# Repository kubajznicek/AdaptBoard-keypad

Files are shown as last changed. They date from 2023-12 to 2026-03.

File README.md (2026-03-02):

# AdaptBoard keypad

Custom macropad with swappable modules, based on Key Boar 2040.
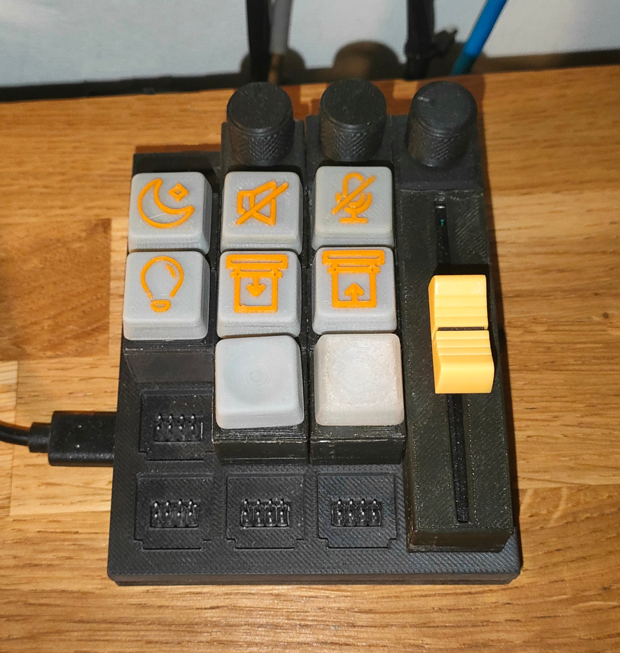
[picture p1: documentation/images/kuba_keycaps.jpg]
AdaptBoard grey keycaps


## Features

- swappable modules
- 4x5 customizable grid
- serial communication

#### Different modules
- key switch module
- potentiometer module
- slide potentiometer module
- lcd module
- joystick module

## Parts list

#### Base of the keypad
- [Kee Boar 2040](https://www.adafruit.com/product/5302)
- [Analog multiplexer](https://www.laskakit.cz/analogovy-multiplexer-16-kanalu-cd74hc4067/)
- custom [PCB](./pcb/)
- 3D printed case
- [pin header](https://www.laskakit.cz/dupont-2x40pin-2-54-mm-pinovy-pas/)*
- [pin header](https://www.laskakit.cz/dupont-40pin-2-54-mm-pinovy-pas/)* for KB2040 and Analog multiplexer
- any USB-C cable

#### Modules
- keyboard switch (any standard keyboard switch should work)
- [potenciometr](https://www.laskakit.cz/psotenciometr-posuvny-10kohm--modul/)*
- [linear potenciometr](https://www.laskakit.cz/potenciometr-rk097n-3-10k-linearni-10k--/)*
- [analog multiplexer](https://www.laskakit.cz/analogovy-multiplexer-16-kanalu-cd74hc4067/)*
- [joystick](https://www.laskakit.cz/joystick-2d-modul/)*
- [OLED display](https://www.laskakit.cz/oled-displej-modry-128x32-0-91--i2c/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)*
- [pin socket](https://www.laskakit.cz/dupont-2x20pin-2-54-mm-pinovy-pas--samice/)* 02x04
- 3D printed keycaps

<sub>*link to Czech e-shop. You may buy elsewhere, just make sure it is the same part model<sub>

## Build your own

for required parts see [Parts list](#parts-list)
Once you have all the parts, you can start building your own AdaptBoard keypad.

#### Soldering

1. Solder pin headers to the Kee Boar 2040 and to the Analog multiplexer
2. Solder first batch of headers to the custom PCB
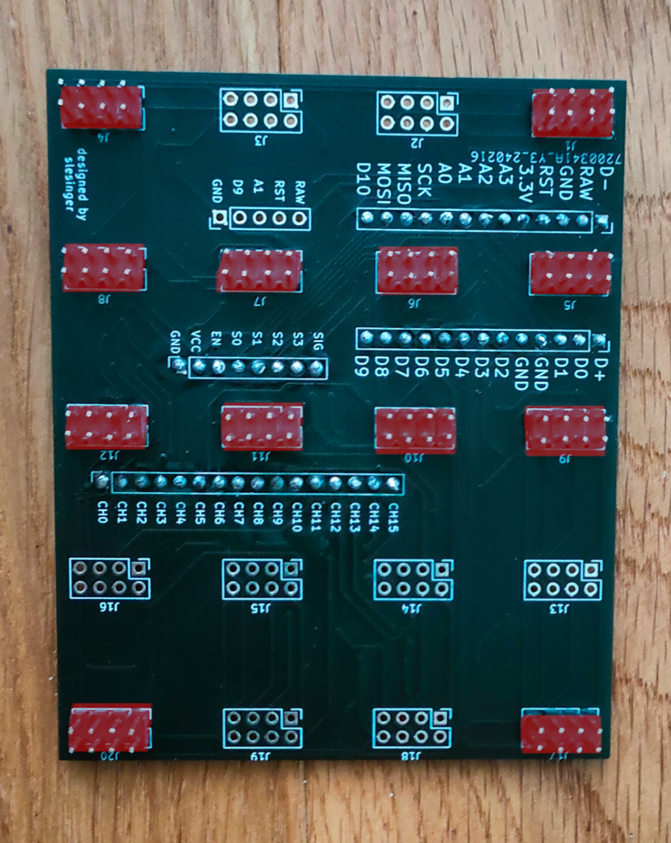
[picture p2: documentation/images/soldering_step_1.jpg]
soldering_step_1

3. Trim the headers on the Kee Boar 2040 and Analog multiplexer, so they are ~1mm above the PCB
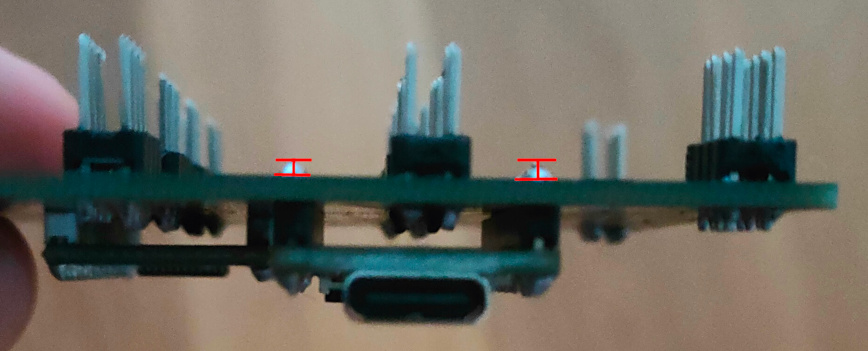
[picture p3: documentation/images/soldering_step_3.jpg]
soldering_step_3

Then solder the Kee Boar 2040 and Analog multiplexer to the back side of the PCB
4. Solder the remaining headers to the PCB

#### Assembling

@TODO

#### Programming
1. Install [CircuitPython](https://learn.adafruit.com/adafruit-kb2040/circuitpython) on your Kee Boar 2040 __Developed and tested on CircuitPython version 8.2.7__
2. Delete the `code.py` file from the CIRCUITPY drive
3. Upload our [firmware](./firmware/) to the CIRCUITPY drive
The final file structure should look like this:
```plaintext
CIRCUITPY
    analog_signal_processor.py
    boot_out.txt #circuitpy system file
    functions.py
    /lib
        /adafruit_display_text
        /adafruit_hid
        adafruit_pixelbuf.mpy
        neopixel.mpy
    main.py
    ssd1306_display.py
```
4. Go to [our App](https://adaptboard-c6996.web.app/) and create your own layout and configuration

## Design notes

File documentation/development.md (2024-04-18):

# Developing for AdaptBoard-keypad

AdaptBoard software is written in CircuitPython 8.2.7, a subset of Python 3. It is designed to be easy to use and to run on microcontrollers with small amounts of RAM and flash memory. CircuitPython is open source and available on [GitHub](https://github.com/adafruit/circuitpython).
[CircuitPython tricks](https://github.com/todbot/circuitpython-tricks)

## Getting Started

To get started, you'll need to install the latest version of CircuitPython for your board. Please follow the instructions in the [KB2040 docs](https://learn.adafruit.com/adafruit-kb2040/circuitpython) to install CircuitPython on your board.

## Dependencies

The following libraries are required for the AdaptBoard-keypad to work:

- adafruit_display_text
- adafruit_hid
- adafruit_pixelbuf.mpy
- neopixel.mpy

## Developing

**⚠️ Warning**

> Adafruit recommends their Mu editor for CircuitPython development, because other IDE may save the files corrupted. However, you can use your IDE of choice and the copy the files onto the board.

copying files to the board

```bash
cp -r main.py /media/$USER/CIRCUITPY/
```

## Enabling and disabling CircuitPython devices

CircuitPython has support for a number of devices. You can enable or disable these devices by editing the `boot.py` file on the CIRCUITPY drive.

```python
import usb_midi # type: ignore
usb_midi.disable()
```

[Adafruit device docs](https://learn.adafruit.com/customizing-usb-devices-in-circuitpython/circuitpy-midi-serial)

If you disabled `storage.disable_usb_drive()` in boot.py, you can enable it by entering safe mode. To enter safe mode, press the reset button twice.

When in safe mode **no code will be executed** and the CIRCUITPY drive will be mounted and you can edit the `boot.py` file.

**⚠️ Warning**

>**`boot.py` is only executed after a hard reset or a power cycle**

[Adafruit safe mode docs](https://learn.adafruit.com/circuitpython-safe-mode/overview)

## Debugging

programs for displaying output from serial port:
- Linux **screen** or **minicom**
- Windows **PuTTY**

### Steps
- Connect the board to your computer using a USB cable.
- The board should appear as a USB drive named CIRCUITPY.
    > If not you can enable it in safe mode by pressing the reset button twice. For more information see [Enabling and disabling CircuitPython devices](#enabling-and-disabling-circuitpython-devices)
- Find the serial port for the board.
    - On Windows, you can use the Device Manager to find the serial port.

    - On Linux, you can use the following command to list the serial ports:

    ```bash
    ls /dev/ttyACM*
    ``` 

- Connect to the serial port using the serial terminal program.
    - On Windows, you can use PuTTY to connect to the serial port.

    - On Linux, you can use the screen command to connect to the serial port.
    ```bash
    sudo screen /dev/ttyACM0 # replace with your port
    ```

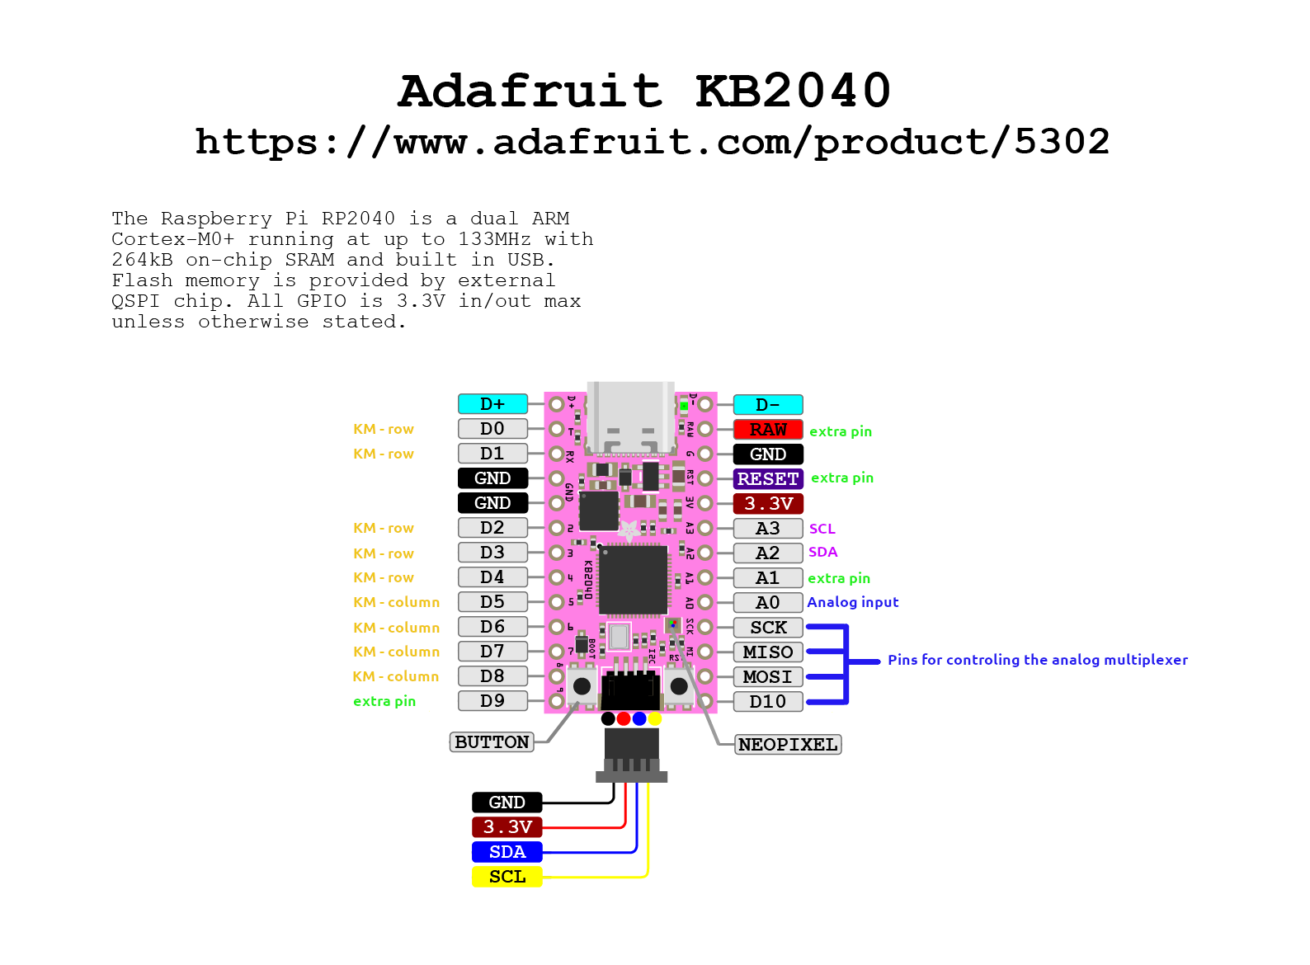
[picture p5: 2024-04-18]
documentation/images/Cutsom_Adafruit_KB2040_Pinout.png

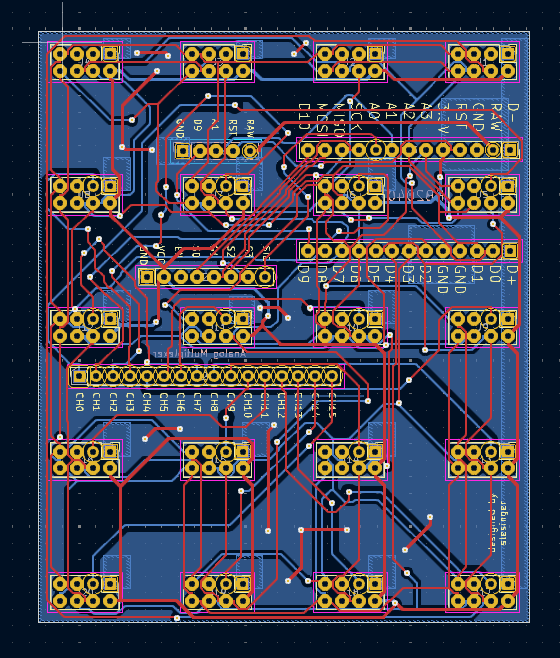
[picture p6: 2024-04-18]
documentation/images/pcb_KiCad_screenshot.png

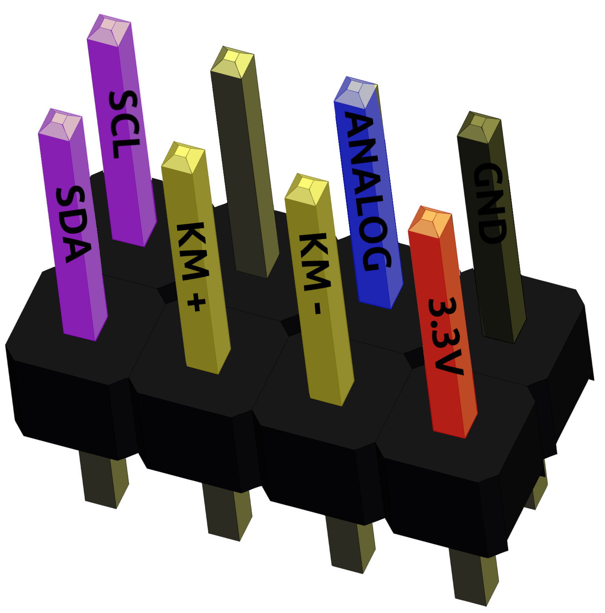
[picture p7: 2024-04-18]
documentation/images/header.png

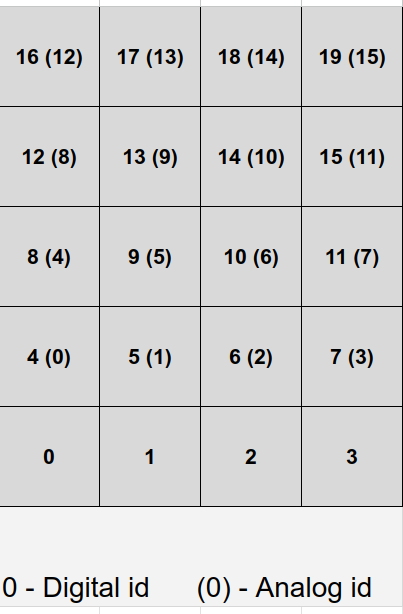
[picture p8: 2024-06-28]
documentation/images/grid_numbers.png

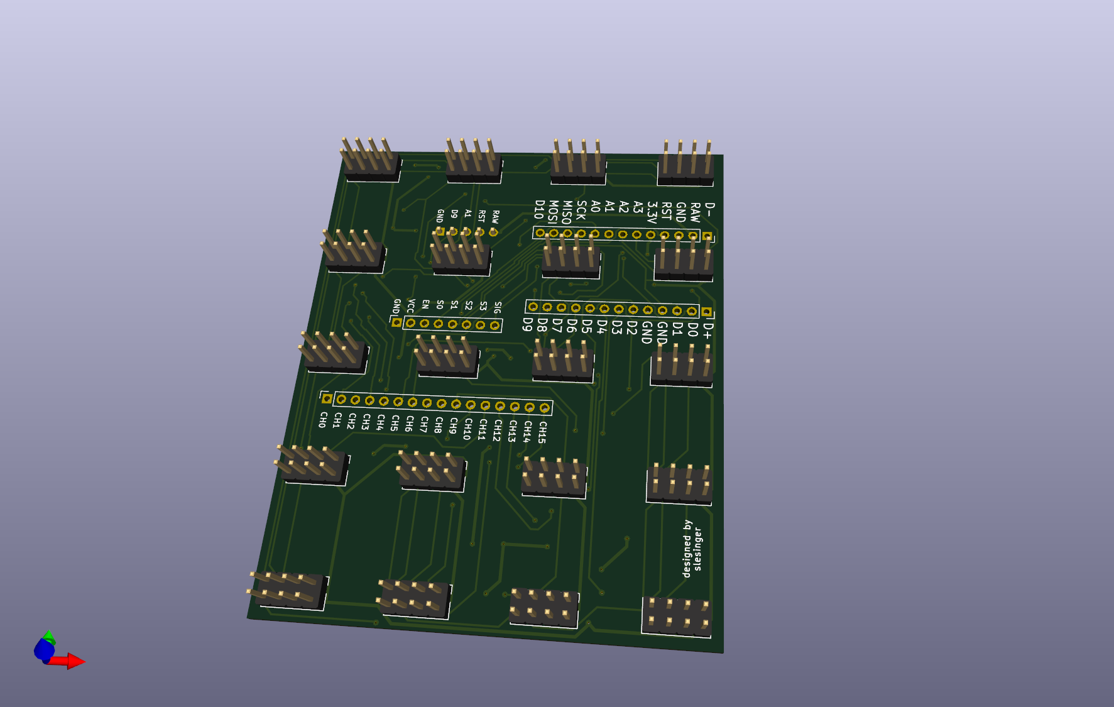
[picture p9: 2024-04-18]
documentation/images/pcb_3D.png

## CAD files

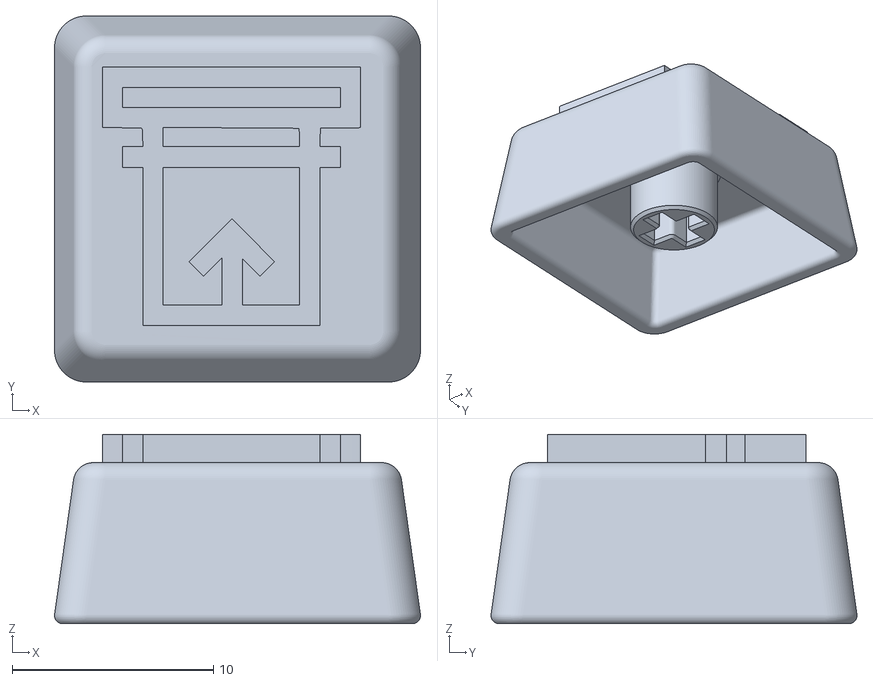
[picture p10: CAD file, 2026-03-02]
Adaptboard-models/keycaps/keycap_window_blind_up.stl
18.2 x 18.2 x 9.40

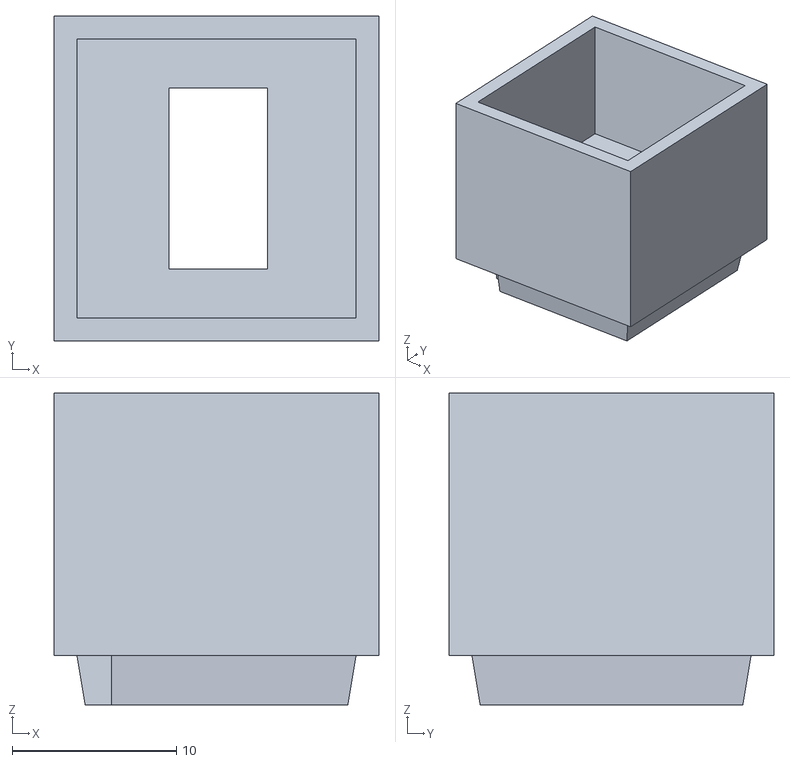
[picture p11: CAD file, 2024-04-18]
Adaptboard-models/Module_1x1_case.stl
19.8 x 19.8 x 19.0

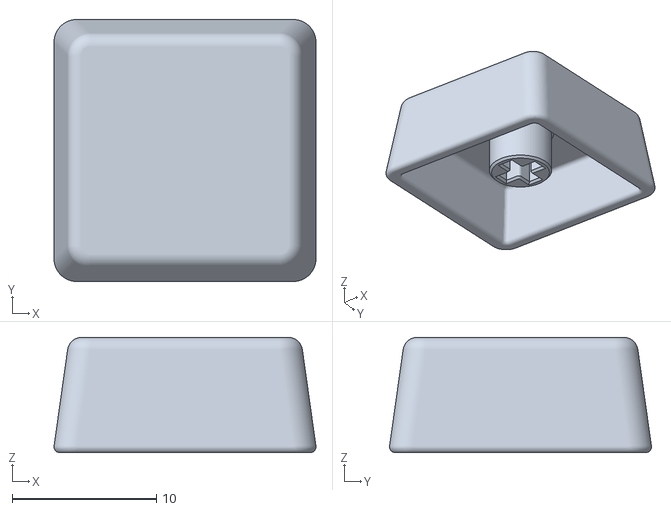
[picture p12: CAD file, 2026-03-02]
Adaptboard-models/keycaps/keycap_flat.stl
18.2 x 18.2 x 8.00

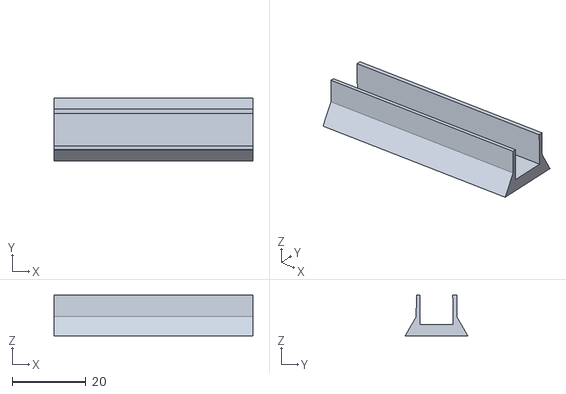
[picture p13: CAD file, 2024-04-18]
Adaptboard-models/Module_4x1_slider_arreter.stl
54.0 x 17.0 x 11.0

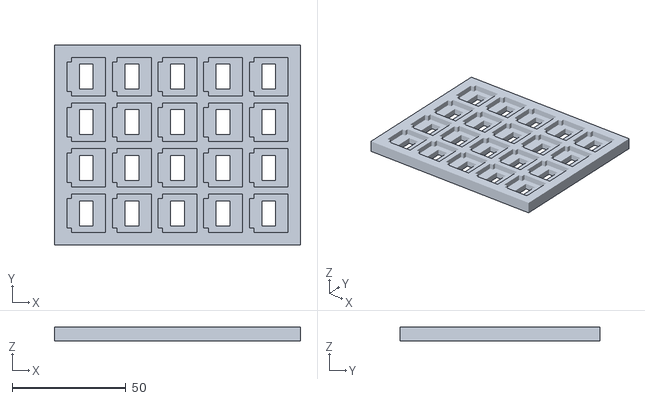
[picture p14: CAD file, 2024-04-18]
Adaptboard-models/Body_grid.stl
108.0 x 88.0 x 6.20

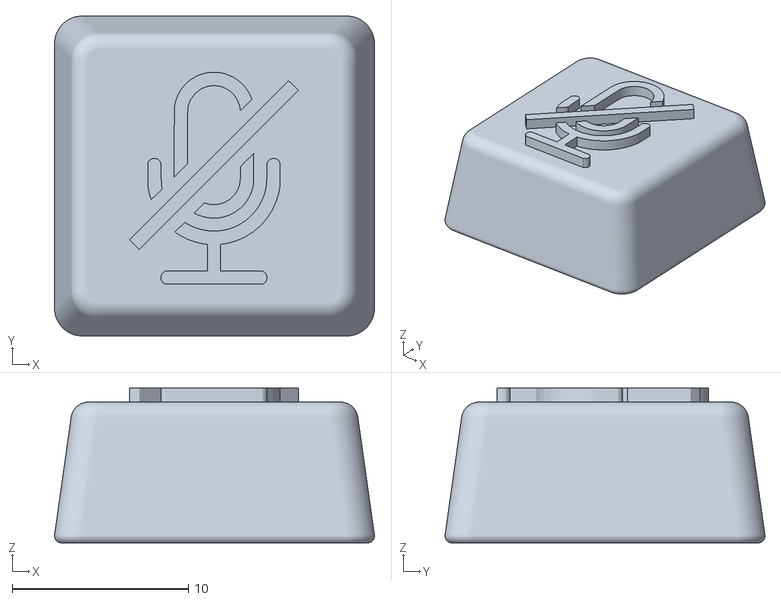
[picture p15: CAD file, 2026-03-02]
Adaptboard-models/keycaps/keycap_mic.stl
18.2 x 18.2 x 8.79

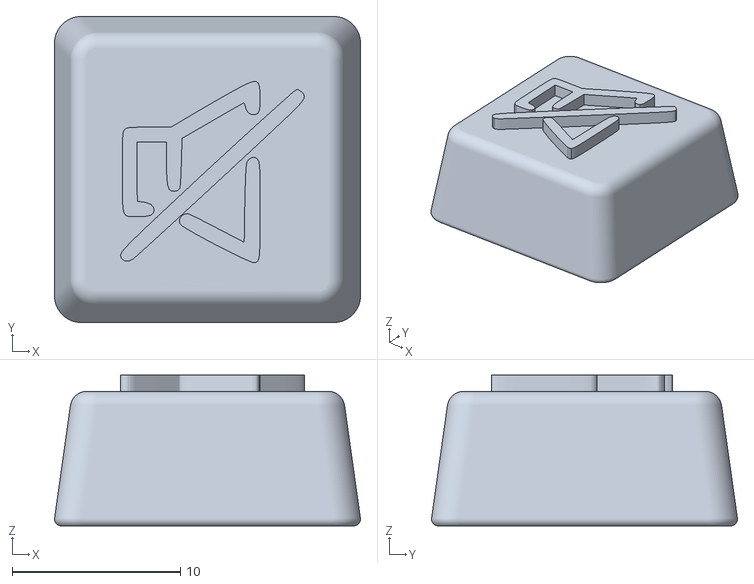
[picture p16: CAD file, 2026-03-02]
Adaptboard-models/keycaps/keycap_mute.stl
18.2 x 18.2 x 8.96

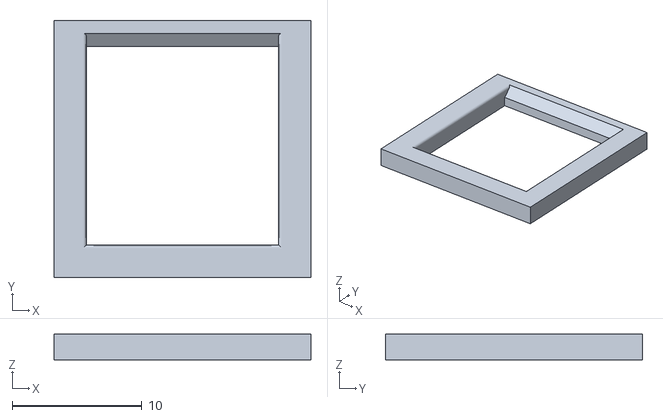
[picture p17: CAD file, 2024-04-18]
Adaptboard-models/Module_1x1_switch_lid.stl
19.8 x 19.8 x 2.00

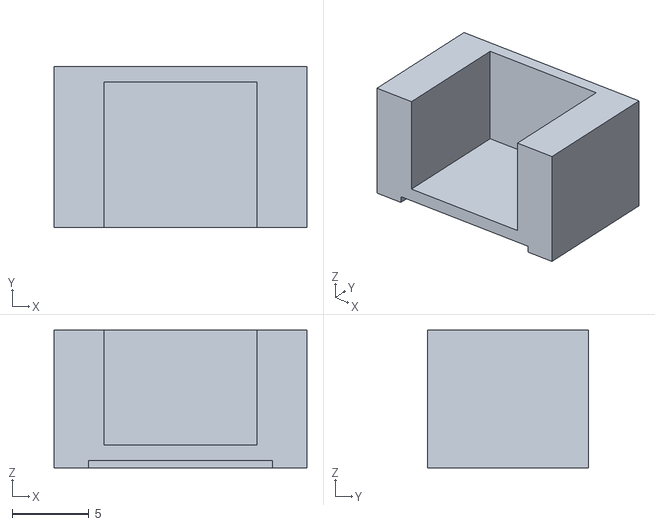
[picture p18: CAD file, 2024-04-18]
Adaptboard-models/Module_1x1_pot_arreter.stl
16.5 x 10.5 x 9.00

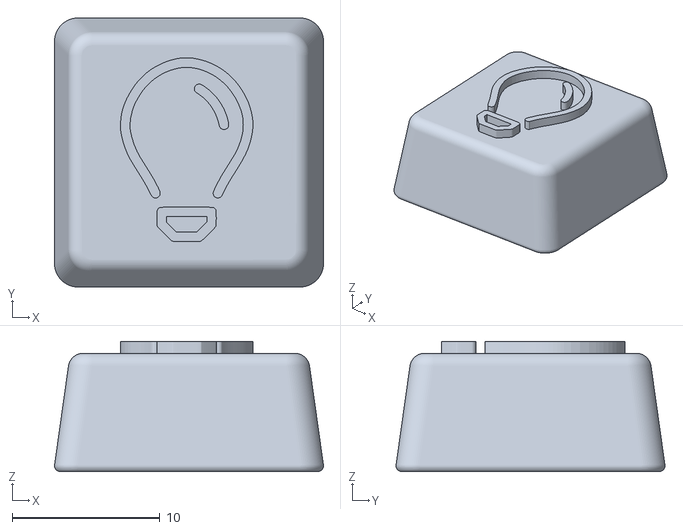
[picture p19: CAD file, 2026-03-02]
Adaptboard-models/keycaps/keycap_lightbulb.stl
18.2 x 18.2 x 8.81

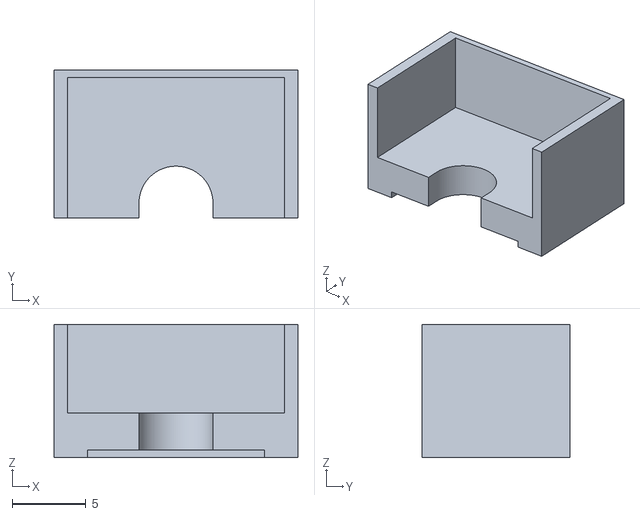
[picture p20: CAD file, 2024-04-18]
Adaptboard-models/Module_1x1_switch_arreter.stl
16.5 x 10.0 x 9.00

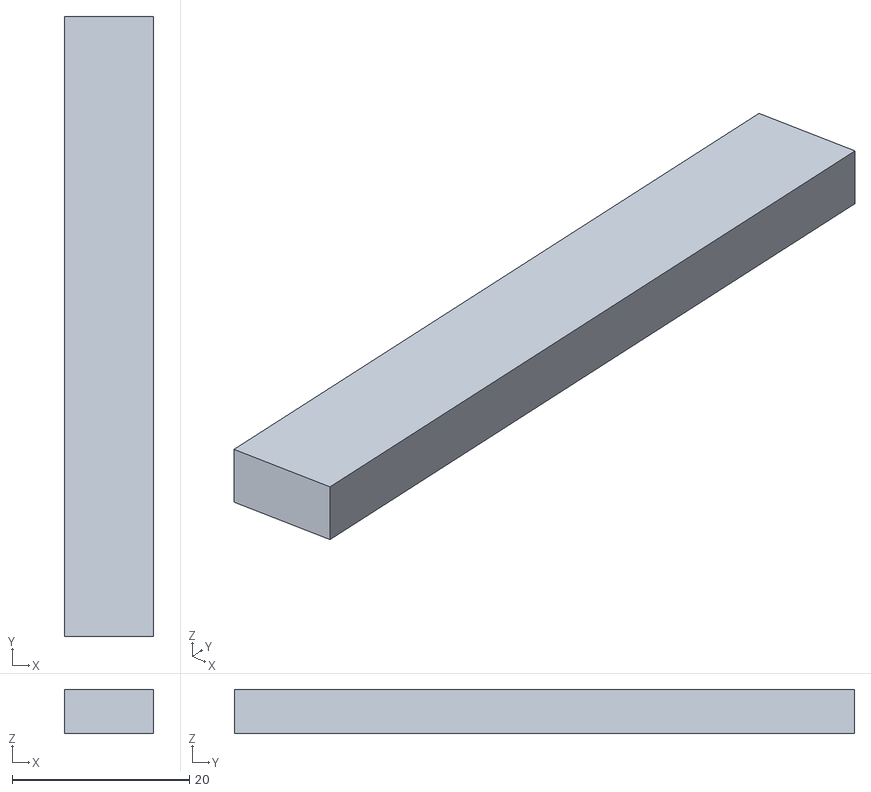
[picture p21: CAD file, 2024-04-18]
Adaptboard-models/Body_foot.stl
10.0 x 70.0 x 5.00

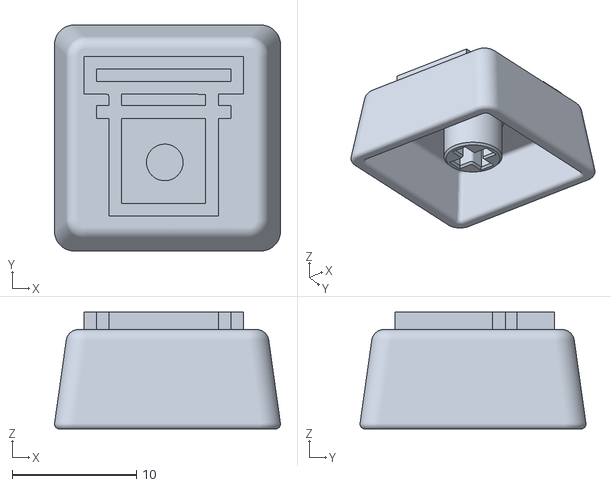
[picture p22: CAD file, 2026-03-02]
Adaptboard-models/keycaps/keycap_window_blind_stop.stl
18.2 x 18.2 x 9.40

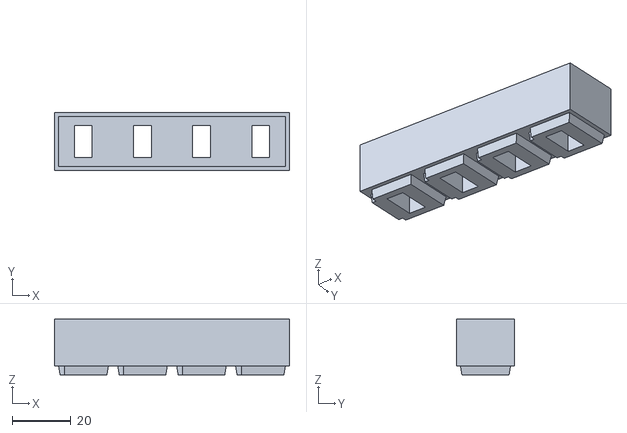
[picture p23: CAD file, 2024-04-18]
Adaptboard-models/Module_4x1_case.stl
79.8 x 19.8 x 19.0

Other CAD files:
Adaptboard-models/keycaps/keycap_window_blind_down.stl
Adaptboard-models/keycaps/keycap_keyboard_light.stl
Adaptboard-models/Body_bottom_cover.stl
Adaptboard-models/keycaps/keycap_discord_mute.stl
Adaptboard-models/AdaptBoard-Keypad.f3d
Adaptboard-models/Body_base.stl
Adaptboard-models/Body_case.stl
Adaptboard-models/Module_1x1_pot_lid.stl
Adaptboard-models/Module_4x1_slider_lid.stl
Adaptboard-models/Pot_soldering_holder.stl
Adaptboard-models/SC- top.stl
Adaptboard-models/keycaps/keycap_sleep.stl

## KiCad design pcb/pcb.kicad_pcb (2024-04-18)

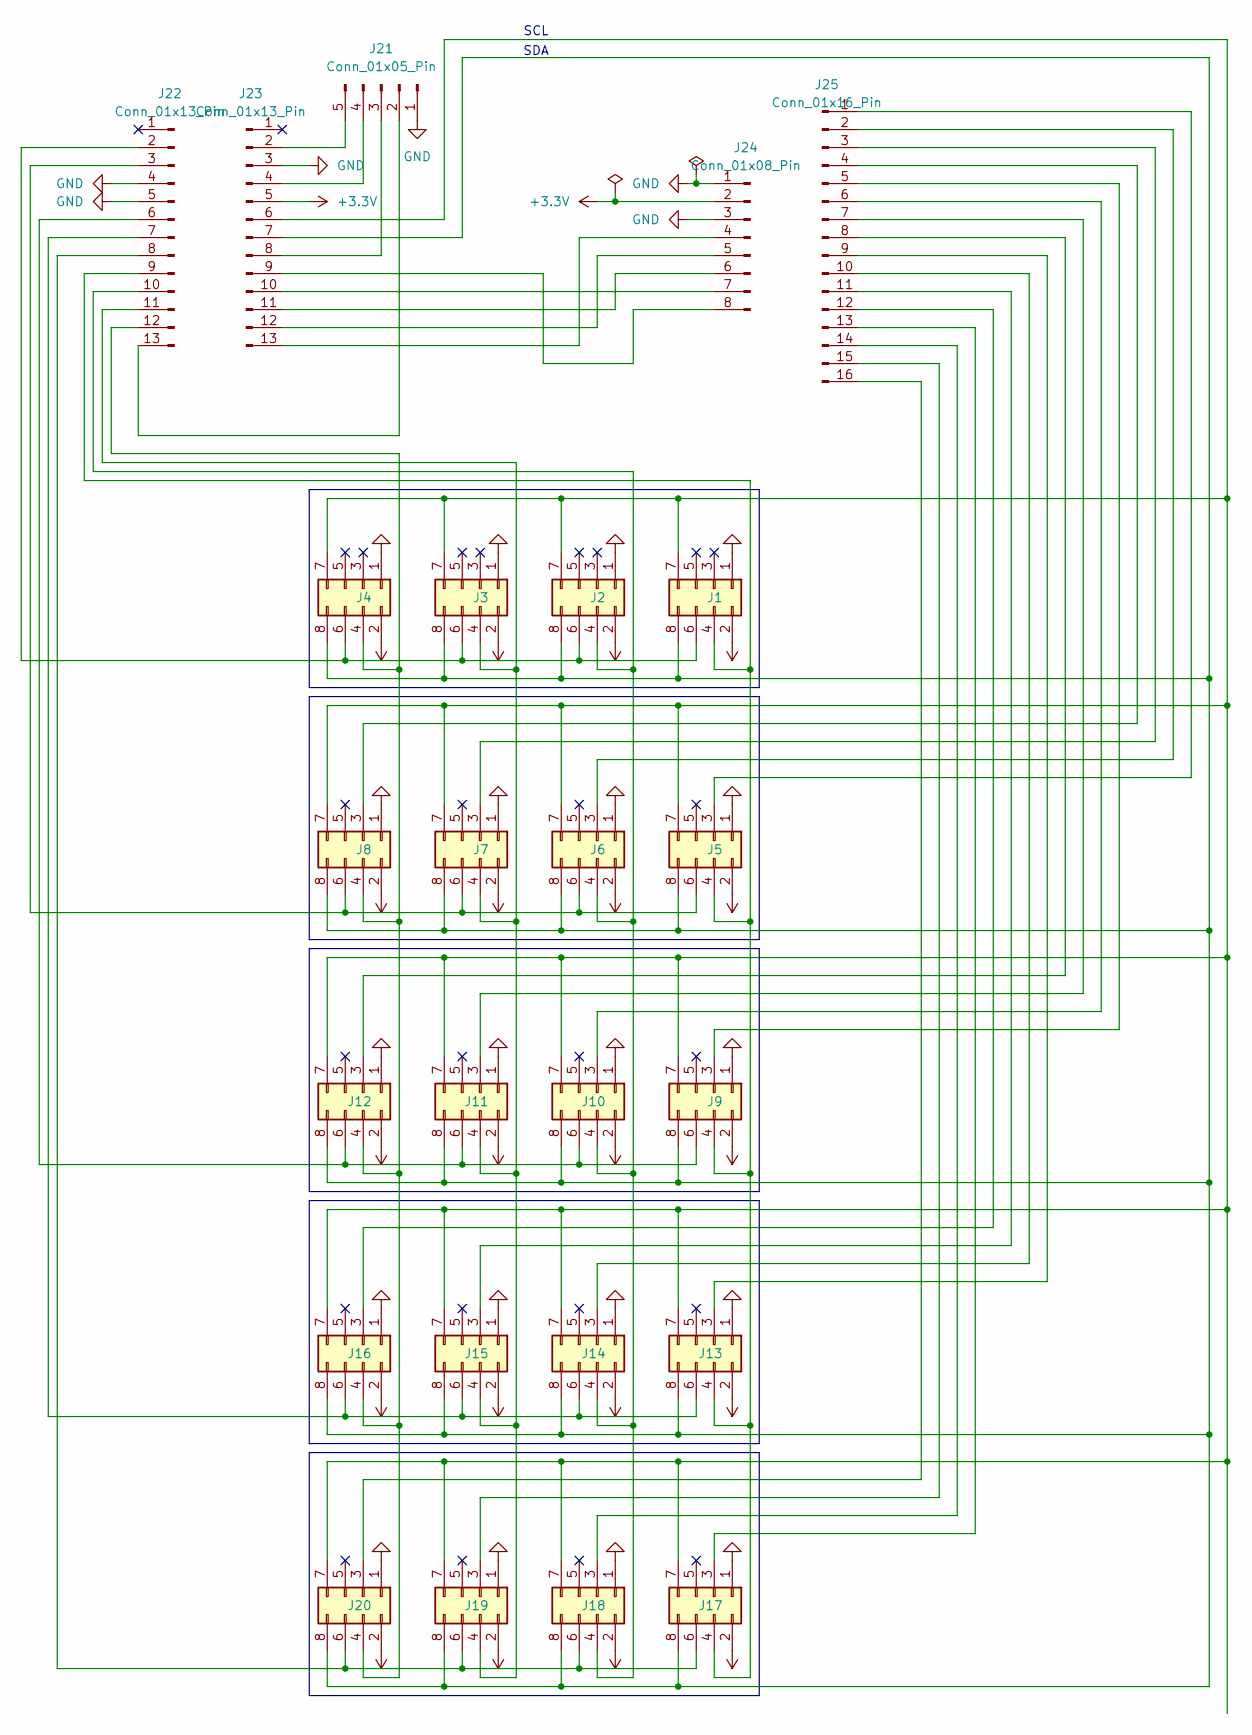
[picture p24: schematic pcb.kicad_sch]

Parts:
J1, J2, J3, J4, J5, J6, J7, J8, J9, J10, J11, J12, J13, J14, J15, J16, J17, J18, J19, J20: Conn_02x04_Odd_Even; PinHeader_2x04_P2.54mm_Vertical
J21: Conn_01x05_Pin; PinHeader_1x05_P2.54mm_Vertical
J22, J23: Conn_01x13_Pin; PinSocket_1x13_P2.54mm_Vertical
J24: Conn_01x08_Pin; PinSocket_1x08_P2.54mm_Vertical
J25: Conn_01x16_Pin; PinSocket_1x16_P2.54mm_Vertical

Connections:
+3.3V: J1.2, J2.2, J3.2, J4.2, J5.2, J6.2, J7.2, J8.2, J9.2, J10.2, J11.2, J12.2, J13.2, J14.2, J15.2, J16.2, J17.2, J18.2, J19.2, J20.2, J23.5, J24.2
GND: J1.1, J2.1, J3.1, J4.1, J5.1, J6.1, J7.1, J8.1, J9.1, J10.1, J11.1, J12.1, J13.1, J14.1, J15.1, J16.1, J17.1, J18.1, J19.1, J20.1, J21.1, J22.4, J22.5, J23.3, J24.1, J24.3
unnamed: J1.4, J5.4, J9.4, J13.4, J17.4, J22.9
unnamed: J1.6, J2.6, J3.6, J4.6, J22.2
unnamed: J1.7, J2.7, J3.7, J4.7, J5.7, J6.7, J7.7, J8.7, J9.7, J10.7, J11.7, J12.7, J13.7, J14.7, J15.7, J16.7, J17.7, J18.7, J19.7, J20.7, J23.6
unnamed: J1.8, J2.8, J3.8, J4.8, J5.8, J6.8, J7.8, J8.8, J9.8, J10.8, J11.8, J12.8, J13.8, J14.8, J15.8, J16.8, J17.8, J18.8, J19.8, J20.8, J23.7
unnamed: J10.3, J25.6
unnamed: J2.4, J6.4, J10.4, J14.4, J18.4, J22.10
unnamed: J9.6, J10.6, J11.6, J12.6, J22.6
unnamed: J11.3, J25.7
unnamed: J3.4, J7.4, J11.4, J15.4, J19.4, J22.11
unnamed: J12.3, J25.8
unnamed: J4.4, J8.4, J12.4, J16.4, J20.4, J22.12
unnamed: J13.3, J25.9
unnamed: J13.6, J14.6, J15.6, J16.6, J22.7
unnamed: J14.3, J25.10
unnamed: J15.3, J25.11
unnamed: J16.3, J25.12
unnamed: J17.3, J25.13
unnamed: J17.6, J18.6, J19.6, J20.6, J22.8
unnamed: J18.3, J25.14
unnamed: J19.3, J25.15
unnamed: J20.3, J25.16
unnamed: J21.2, J22.13
unnamed: J21.3, J23.8
unnamed: J21.4, J23.4
unnamed: J21.5, J23.2
unnamed: J5.6, J6.6, J7.6, J8.6, J22.3
unnamed: J23.9, J24.8
unnamed: J23.10, J24.7
unnamed: J23.11, J24.6
unnamed: J23.12, J24.5
unnamed: J23.13, J24.4
unnamed: J5.3, J25.1
unnamed: J6.3, J25.2
unnamed: J7.3, J25.3
unnamed: J8.3, J25.4
unnamed: J9.3, J25.5

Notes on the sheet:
SCL
SDA

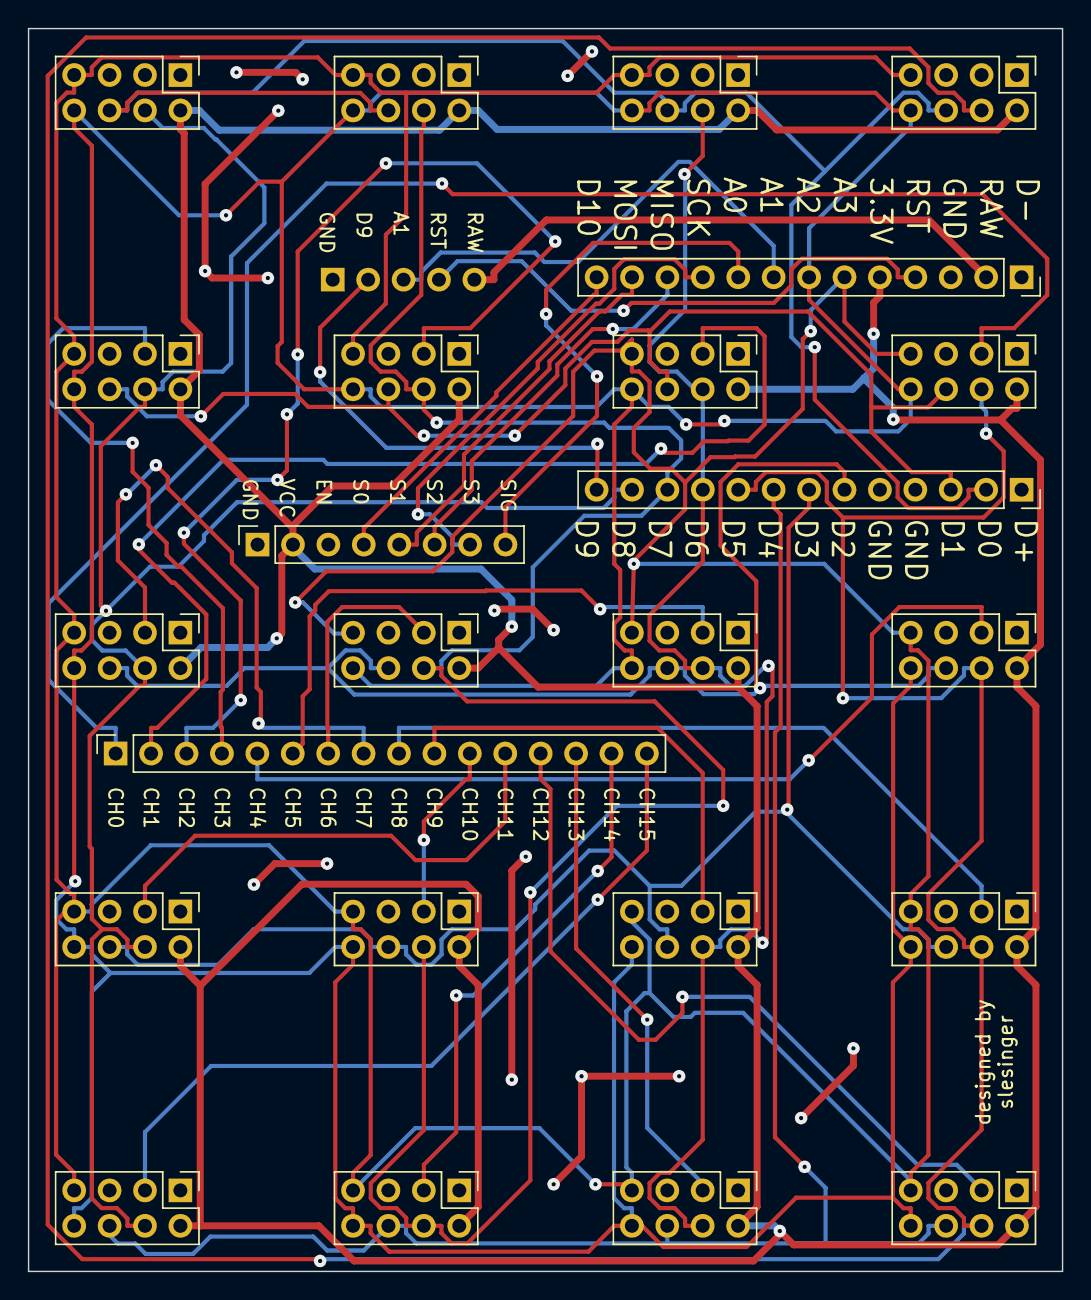
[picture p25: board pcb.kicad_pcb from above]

Board: 2 copper layers, 74.2 x 89.1 mm, 25 parts (1 on the bottom side), 38 nets.

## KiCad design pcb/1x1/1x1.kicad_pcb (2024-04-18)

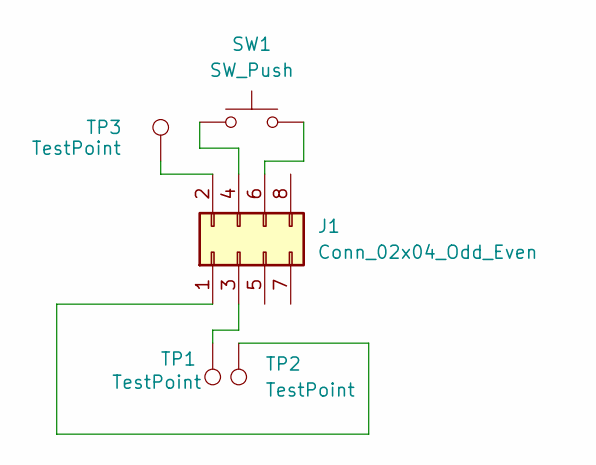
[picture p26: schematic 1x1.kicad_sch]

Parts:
J1: Conn_02x04_Odd_Even; PinSocket_2x04_P2.54mm_Vertical
SW1: SW_Push; SW_Cherry_MX_Plate
TP1, TP2, TP3: TestPoint; TestPoint_Pad_1.5x1.5mm

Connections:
unnamed: J1.1, TP2.1
unnamed: J1.2, TP3.1
unnamed: J1.3, TP1.1
unnamed: J1.4, SW1.1
unnamed: J1.6, SW1.2

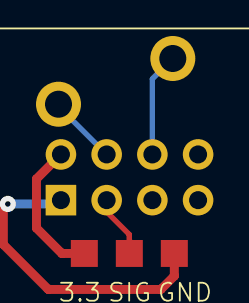
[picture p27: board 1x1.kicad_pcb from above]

Board: 2 copper layers, 5 parts (1 on the bottom side), 5 nets.

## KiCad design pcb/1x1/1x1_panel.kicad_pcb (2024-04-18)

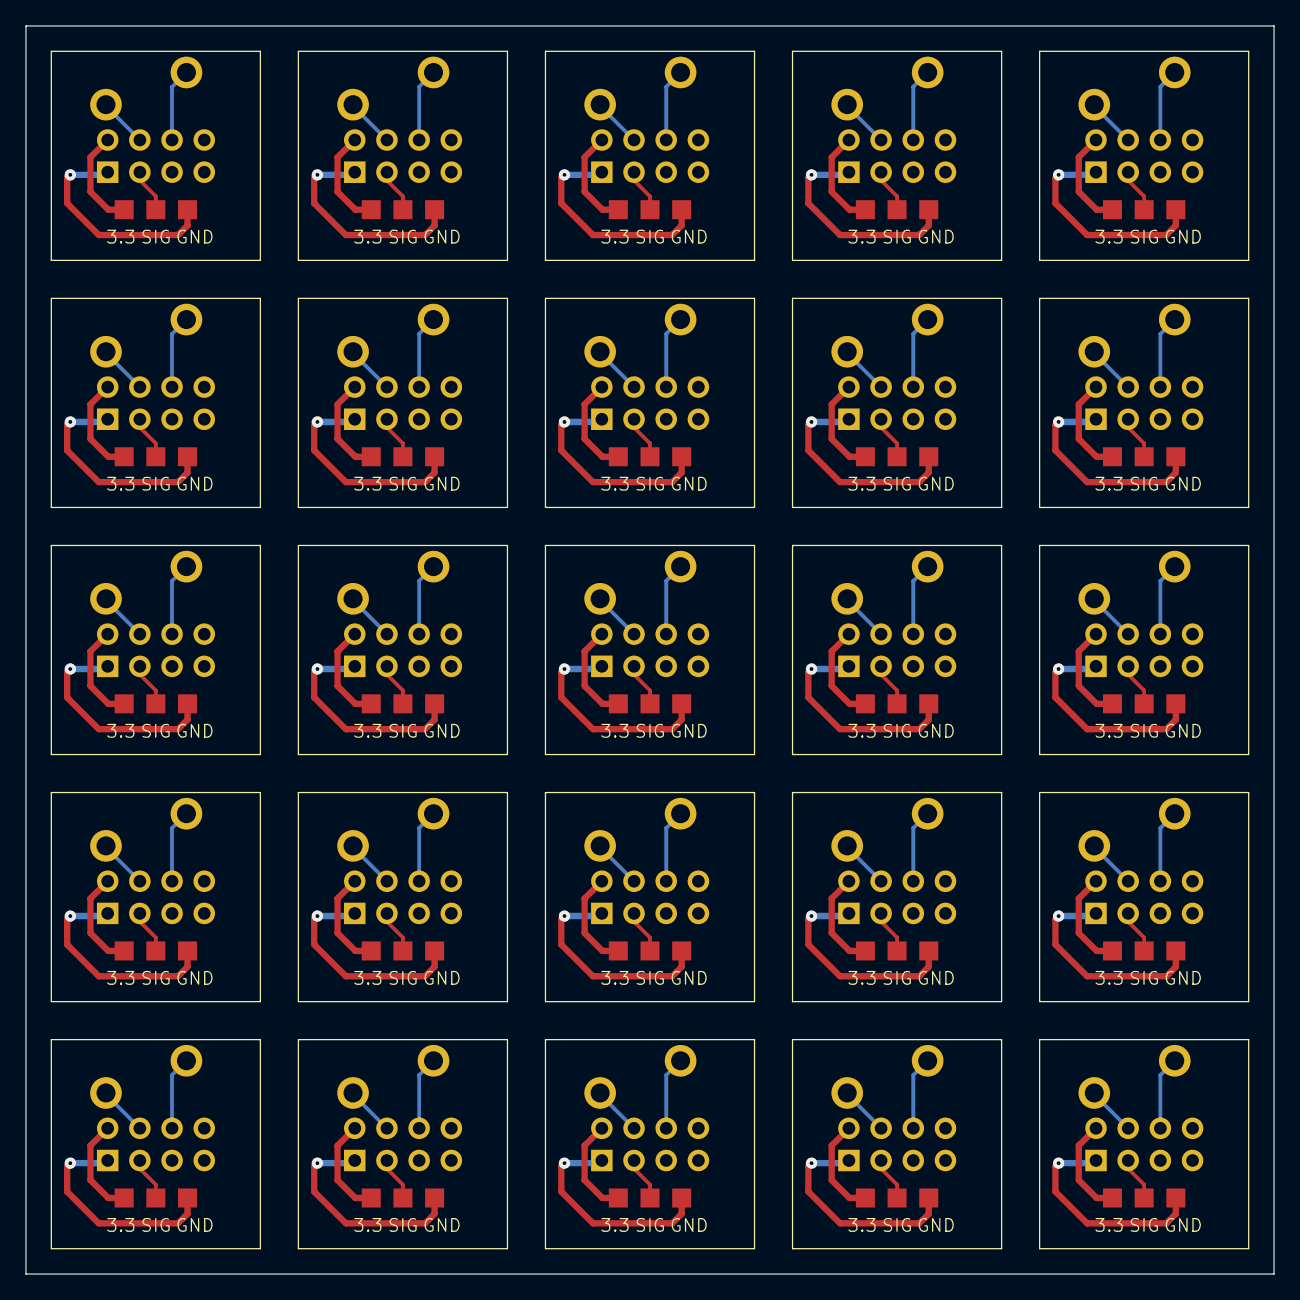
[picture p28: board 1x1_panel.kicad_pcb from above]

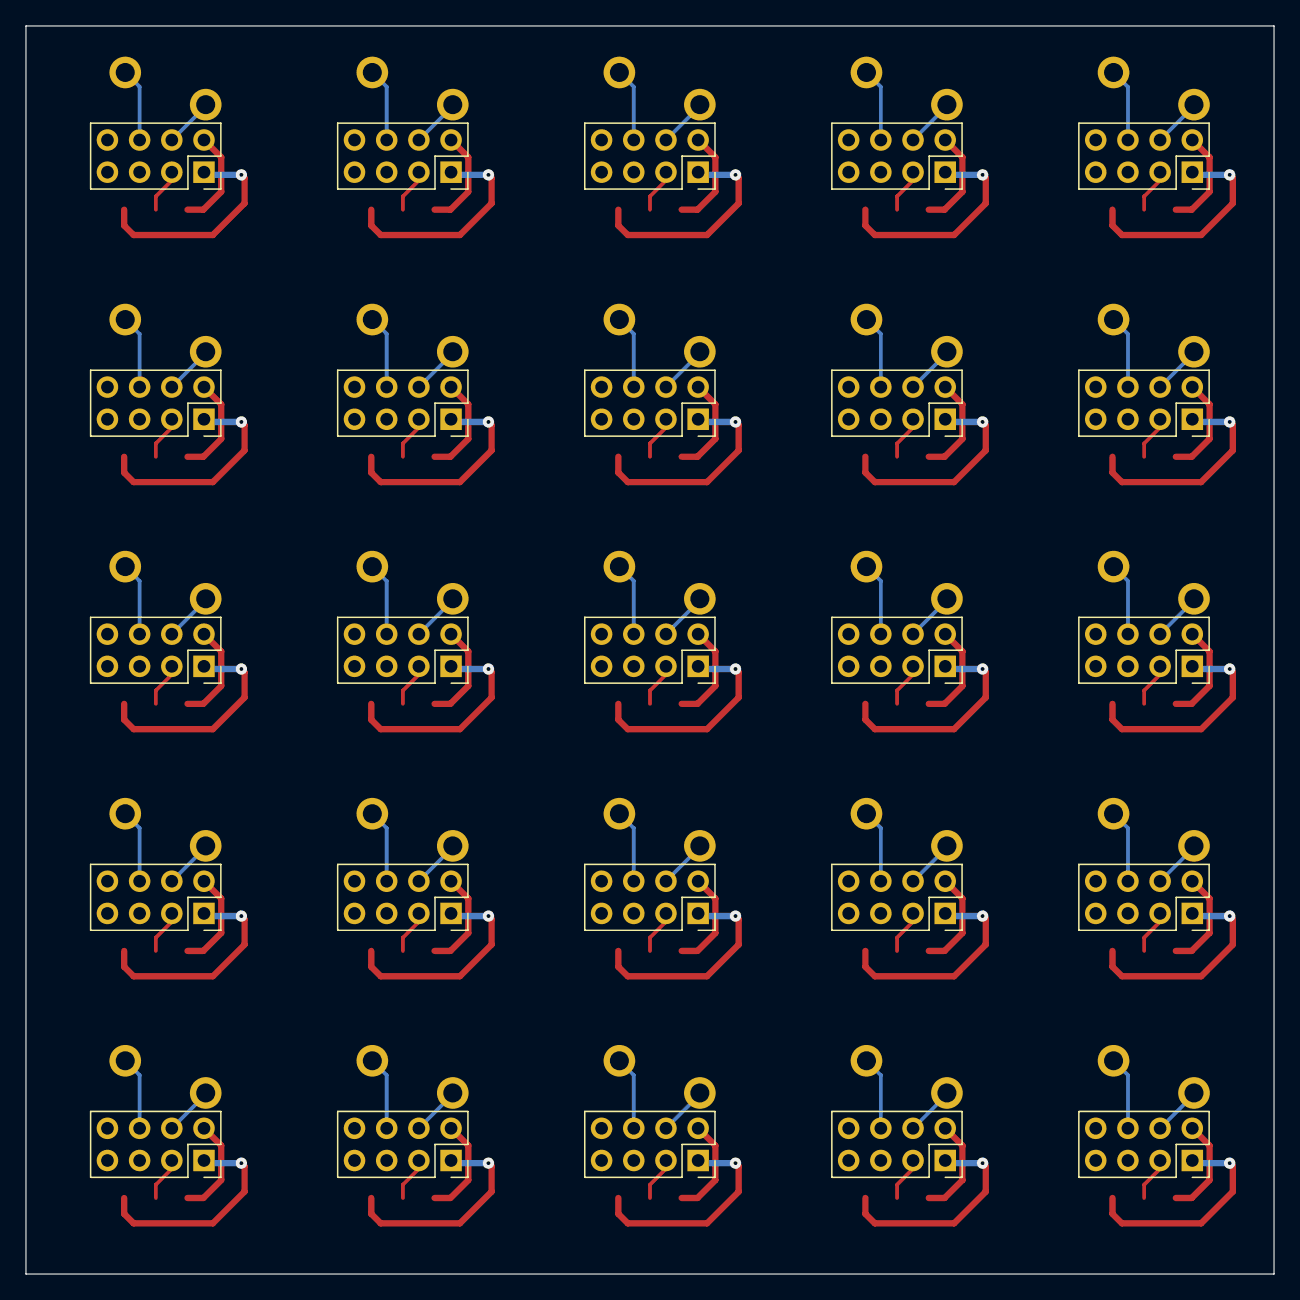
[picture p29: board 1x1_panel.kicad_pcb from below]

Board: 2 copper layers, 98.5 x 98.5 mm, 125 parts (25 on the bottom side), 5 nets.

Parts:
J1, J1#2, J2, J3, J4, J5, J6, J7, J8, J9, J10, J11, J12, J13, J14, J15, J16, J17, J18, J19, J20, J21, J22, J23, J24: Conn_02x04_Odd_Even; PinSocket_2x04_P2.54mm_Vertical
SW1, SW1#2, SW2, SW3, SW4, SW5, SW6, SW7, SW8, SW9, SW10, SW11, SW12, SW13, SW14, SW15, SW16, SW17, SW18, SW19, SW20, SW21, SW22, SW23, SW24: SW_Push; SW_Cherry_MX_Plate
TP1, TP1#2, TP2, TP2#2, TP3, TP3#2, TP4, TP5, TP6, TP7, TP8, TP9, TP10, TP11, TP12, TP13, TP14, TP15, TP16, TP17, TP18, TP19, TP20, TP21, TP22, TP23, TP24, TP25, TP26, TP27, TP28, TP29, TP30, TP31, TP32, TP33, TP34, TP35, TP36, TP37, TP38, TP39, TP40, TP41, TP42, TP43, TP44, TP45, TP46, TP47, TP48, TP49, TP50, TP51, TP52, TP53, TP54, TP55, TP56, TP57, TP58, TP59, TP60, TP61, TP62, TP63, TP64, TP65, TP66, TP67, TP68, TP69, TP70, TP71, TP72: TestPoint; TestPoint_Pad_1.5x1.5mm

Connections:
unnamed: J1.1, J1#2.1, J2.1, J3.1, J4.1, J5.1, J6.1, J7.1, J8.1, J9.1, J10.1, J11.1, J12.1, J13.1, J14.1, J15.1, J16.1, J17.1, J18.1, J19.1, J20.1, J21.1, J22.1, J23.1, J24.1, TP2.1, TP2#2.1, TP5.1, TP8.1, TP11.1, TP14.1, TP17.1, TP20.1, TP23.1, TP26.1, TP29.1, TP32.1, TP35.1, TP38.1, TP41.1, TP44.1, TP47.1, TP50.1, TP53.1, TP56.1, TP59.1, TP62.1, TP65.1, TP68.1, TP71.1
unnamed: J1.2, J1#2.2, J2.2, J3.2, J4.2, J5.2, J6.2, J7.2, J8.2, J9.2, J10.2, J11.2, J12.2, J13.2, J14.2, J15.2, J16.2, J17.2, J18.2, J19.2, J20.2, J21.2, J22.2, J23.2, J24.2, TP3.1, TP3#2.1, TP6.1, TP9.1, TP12.1, TP15.1, TP18.1, TP21.1, TP24.1, TP27.1, TP30.1, TP33.1, TP36.1, TP39.1, TP42.1, TP45.1, TP48.1, TP51.1, TP54.1, TP57.1, TP60.1, TP63.1, TP66.1, TP69.1, TP72.1
unnamed: J1.3, J1#2.3, J2.3, J3.3, J4.3, J5.3, J6.3, J7.3, J8.3, J9.3, J10.3, J11.3, J12.3, J13.3, J14.3, J15.3, J16.3, J17.3, J18.3, J19.3, J20.3, J21.3, J22.3, J23.3, J24.3, TP1.1, TP1#2.1, TP4.1, TP7.1, TP10.1, TP13.1, TP16.1, TP19.1, TP22.1, TP25.1, TP28.1, TP31.1, TP34.1, TP37.1, TP40.1, TP43.1, TP46.1, TP49.1, TP52.1, TP55.1, TP58.1, TP61.1, TP64.1, TP67.1, TP70.1
unnamed: J1.4, J1#2.4, J2.4, J3.4, J4.4, J5.4, J6.4, J7.4, J8.4, J9.4, J10.4, J11.4, J12.4, J13.4, J14.4, J15.4, J16.4, J17.4, J18.4, J19.4, J20.4, J21.4, J22.4, J23.4, J24.4, SW1.1, SW1#2.1, SW2.1, SW3.1, SW4.1, SW5.1, SW6.1, SW7.1, SW8.1, SW9.1, SW10.1, SW11.1, SW12.1, SW13.1, SW14.1, SW15.1, SW16.1, SW17.1, SW18.1, SW19.1, SW20.1, SW21.1, SW22.1, SW23.1, SW24.1
unnamed: J1.6, J1#2.6, J2.6, J3.6, J4.6, J5.6, J6.6, J7.6, J8.6, J9.6, J10.6, J11.6, J12.6, J13.6, J14.6, J15.6, J16.6, J17.6, J18.6, J19.6, J20.6, J21.6, J22.6, J23.6, J24.6, SW1.2, SW1#2.2, SW2.2, SW3.2, SW4.2, SW5.2, SW6.2, SW7.2, SW8.2, SW9.2, SW10.2, SW11.2, SW12.2, SW13.2, SW14.2, SW15.2, SW16.2, SW17.2, SW18.2, SW19.2, SW20.2, SW21.2, SW22.2, SW23.2, SW24.2

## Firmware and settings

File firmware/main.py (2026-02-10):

import board # type: ignore
import keypad  # type: ignore
import busio # type: ignore
import displayio # type: ignore

# lib imports
import neopixel # type: ignore
import usb_hid  # type: ignore
from adafruit_hid.consumer_control import ConsumerControl # type: ignore
from adafruit_hid.keyboard import Keyboard  # type: ignore
from adafruit_hid.mouse import Mouse  # type: ignore
from adafruit_hid.keyboard_layout_us import KeyboardLayoutUS # type: ignore

# local imports
from config import MATRIX_ACTIONS, ANALOG_ACTIONS, DISPLAY_CONFIG
from functions import start_up_blink
from analog_signal_processor import AnalogSignalProcessor
if DISPLAY_CONFIG["present"]:
    from ssd1306_display import ssd1306_display as display


displayio.release_displays()

matrix = keypad.KeyMatrix([board.D0, board.D1, board.D2, board.D3, board.D4], [board.D5, board.D6, board.D7, board.D8])   # https://docs.circuitpython.org/en/latest/shared-bindings/keypad/index.html#keypad.KeyMatrix
pixels = neopixel.NeoPixel(board.NEOPIXEL, 1)   # https://learn.adafruit.com/adafruit-kb2040/neopixel-led
cc = ConsumerControl(usb_hid.devices)
kbd = Keyboard(usb_hid.devices)
layout = KeyboardLayoutUS(kbd)
mouse = Mouse(usb_hid.devices)
if DISPLAY_CONFIG["present"]:
    i2c = busio.I2C(board.A3, board.A2)     # https://docs.circuitpython.org/en/latest/shared-bindings/busio/index.html
    my_display = display(i2c, 0x3C, DISPLAY_CONFIG)



if DISPLAY_CONFIG["present"]:
    my_display.render_text("Hello World!", 28, DISPLAY_CONFIG["HEIGHT"] // 2 - 1)
    # my_display.render_image("./test.bmp")

CHANNELS = []   # list of channels to be scanned
for key in ANALOG_ACTIONS.keys():
    CHANNELS.append(key)

my_analog = AnalogSignalProcessor(board.A0, (board.D10, board.MOSI, board.MISO, board.SCK), CHANNELS, 4)

print("Starting main loop")
start_up_blink(pixels)
while True:
    # scan the keypad matrix
    key_event = matrix.events.get()

    if key_event and key_event.pressed:
        key_action = MATRIX_ACTIONS.get(key_event.key_number, False)
        if key_action:
            key_action(cc, kbd, layout) # type: ignore
        else:
            print(f"WARNING!  -  Key {key_event.key_number} not configured")


    #region Analog Read
    for channel in CHANNELS:
        my_analog.set_channel(channel)
        current_value = my_analog.read_analog()

        # process the new reading
        smoothed_value = my_analog.process_new_reading(channel, current_value)
        current_step = my_analog.calculate_current_step(channel, smoothed_value)

        # check if the step has changed
        if my_analog.channel_state[channel] == current_step:
            continue

        # if the step has changed, perform the action
        increased = my_analog.channel_state[channel] < current_step
        current_step_number = my_analog.__channel_settings[channel]["steps"] - int(current_step / my_analog.__channel_settings[channel]["step_size"])
        ANALOG_ACTIONS[channel][increased](cc, kbd, mouse, current_step_number)

        # update the channel state
        my_analog.channel_state[channel] = current_step
    #endregion

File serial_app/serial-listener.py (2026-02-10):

import json
import subprocess
import sys
import serial
import time

CONFIG_PATH = "/home/jakub/Documents/projekt/AdaptBoard-keypad/serial_app/config.json"

# Throttle analog events to avoid flooding expensive actions (pactl/osd).
ANALOG_MIN_INTERVAL = 0.02
ANALOG_MIN_DELTA = 0

# Warning thresholds for always-on listener
WARN_RATE_WINDOW = 1.0
WARN_MSG_RATE = 80  # messages per second
WARN_NOISY_ANALOG = 30  # noisy analog events per second per channel
WARN_COOLDOWN = 10.0  # seconds

def notify_warning(title, message, warn_state):
    now = time.monotonic()
    last = warn_state.get("last_warn", 0.0)
    if (now - last) < WARN_COOLDOWN:
        return
    warn_state["last_warn"] = now
    try:
        subprocess.Popen(["notify-send", title, message])
    except Exception:
        pass

def load_config():
    with open(CONFIG_PATH, "r", encoding="utf-8") as f:
        return json.load(f)

def run_action(action, value=None):
    shell_cmd = action.get("shell")
    if not shell_cmd:
        return
    if action.get("pass_value") and value is not None:
        suffix = action.get("suffix", "")
        shell_cmd = f"{shell_cmd} {value}{suffix}"
    subprocess.Popen(shell_cmd, shell=True)

def handle_event(evt, actions, analog_state=None, warn_state=None):
    evt_type = evt.get("type")
    evt_id = str(evt.get("id"))

    if evt_type == "key":
        action = actions.get("key", {}).get(evt_id)
        if not action:
            return
        required_state = action.get("state")
        if required_state and evt.get("state") != required_state:
            return
        run_action(action)

    elif evt_type == "analog":
        action = actions.get("analog", {}).get(evt_id)
        if not action:
            return
        value = evt.get("value")
        if value is None:
            return
        try:
            value = float(value)
        except (TypeError, ValueError):
            return
        factor = action.get("factor")
        if factor is not None:
            try:
                value = value * float(factor)
            except (TypeError, ValueError):
                return
        if isinstance(value, float) and value.is_integer():
            value = int(value)
        if analog_state is not None:
            state = analog_state.setdefault(evt_id, {"last_time": 0.0, "last_value": None})
            now = time.monotonic()
            last_value = state["last_value"]
            if last_value is not None:
                if abs(value - last_value) < ANALOG_MIN_DELTA and (now - state["last_time"]) < ANALOG_MIN_INTERVAL:
                    return
            state["last_time"] = now
            state["last_value"] = value
            if warn_state is not None:
                noisy = warn_state.setdefault("noisy", {})
                bucket = noisy.setdefault(evt_id, {"start": now, "count": 0})
                if (now - bucket["start"]) > WARN_RATE_WINDOW:
                    bucket["start"] = now
                    bucket["count"] = 0
                bucket["count"] += 1
                if bucket["count"] > WARN_NOISY_ANALOG:
                    notify_warning(
                        "Serial listener warning",
                        f"Noisy analog channel {evt_id}: {bucket['count']}/s",
                        warn_state,
                    )
        run_action(action, value=value)

def main():
    cfg = load_config()
    serial_cfg = cfg.get("serial", {})
    actions = cfg.get("actions", {})

    port = serial_cfg.get("port", "/dev/ttyACM0")
    baud = serial_cfg.get("baud", 115200)
    timeout = serial_cfg.get("timeout", 1)

    analog_state = {}
    warn_state = {"last_warn": 0.0, "rate": {"start": time.monotonic(), "count": 0}, "noisy": {}}

    with serial.Serial(port, baud, timeout=timeout) as ser:
        while True:
            line = ser.readline()
            if not line:
                continue
            try:
                text = line.decode("utf-8", errors="replace").strip()
                evt = json.loads(text)
            except Exception:
                continue
            rate = warn_state.get("rate")
            now = time.monotonic()
            if (now - rate["start"]) > WARN_RATE_WINDOW:
                rate["start"] = now
                rate["count"] = 0
            rate["count"] += 1
            if rate["count"] > WARN_MSG_RATE:
                notify_warning(
                    "Serial listener warning",
                    f"High serial message rate: {rate['count']}/s",
                    warn_state,
                )
            handle_event(evt, actions, analog_state, warn_state)

if __name__ == "__main__":
    try:
        main()
    except KeyboardInterrupt:
        pass

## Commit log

2023-11-12 fix SetChannel function, add LogChannel function, cc for testing
    [functions.py, main.py]
2023-11-23 add custom pinout, tested spi pins for multiplexer control
2023-11-23 add kicad pcb folder
    [pcb.kicad_pcb, pcb.kicad_sch]
2023-11-24 add multiplexer symbol
    [pcb.kicad_sch]
2023-11-26 pcb schema
    [pcb.kicad_pcb, pcb.kicad_sch]
2023-12-01 Kuba CircuitPython code (#1)
    * kuba branch
    * ben
    * functions for reading chnnels from analog multiplexer
    * fix SetChannel function, add LogChannel function, cc for testing
    * fix SetChannel function
    * add adafruit_hid lib
    * pinout png, keypad matrix
    * scaning multiplexer ports
    * time.spleep decreased, add TODO
    * naming conventions, AnalogSignalProcessor class
    * benchmark
    * experiment with triggered times in analog readings
    * add custom pinout, tested spi pins for multiplexer control
    * add kicad pcb folder
    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
    [pcb.kicad_pcb, pcb.kicad_sch]
2023-12-01 fixed pin rotation on custom components
    [pcb.kicad_sch]
2023-12-02 add pcb footprints to pin headers
    [pcb.kicad_sch]
2023-12-09 current_value in analog read loop
2023-12-11 header in documentation fixed, pcb schematic done
    [pcb.kicad_pcb, pcb.kicad_sch]
2023-12-15 pcb edge cuts
    [pcb.kicad_pcb]
2023-12-21 Create a file that can be loaded into the Board, 1st version
2024-01-15 pcb component placement
    [pcb.kicad_pcb, pcb.kicad_sch]
2024-01-16 first routing design
    [pcb.kicad_pcb, pcb.kicad_sch]
2024-01-24 pcb autosave, git ignore update
    [pcb.kicad_pcb]
2024-01-31 fix multiplexer pin sockets placement
    [pcb.kicad_pcb, pcb.kicad_sch]
2024-02-04 display config, key not conigerd not longer crashes the main loop
    [config.py, functions.py, main.py]
2024-02-07 updated pcb, 1x1 pcb
    [1x1.kicad_pcb, 1x1.kicad_sch, pcb.kicad_pcb]
2024-02-13 moved 1x1 pcb folder
    [1x1.kicad_pcb, 1x1.kicad_sch, pcb.kicad_pcb]
2024-02-15 1x1 pcb updated
    [1x1.kicad_pcb, 1x1.kicad_sch]
2024-02-15 pcb v2
    [pcb.kicad_pcb]
2024-02-29 PCB v2, firmware - analog steps (#5)
    * lukas branch
    * Schafl, dve zkratky
    * autohotkey trigger
    * add multiplexer symbol
    * add matrix config file
    * pcb schema
    *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
    [1x1.kicad_pcb, 1x1.kicad_sch, pcb.kicad_pcb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]
2024-03-02 kicad version 8.0, 1x1 pcb
    [1x1.kicad_pcb, 1x1.kicad_sch]
2024-03-14 Whole Keyboard buttons available
2024-03-14 settings of AD-Board buttons - Potmetr
    working settings when selected Potmetr
    created files for other settings
2024-03-15 Mainly design for Display, Shuffle, Switch - text, Fn actions
    Display - functional = set display to true
    Shuffle - functional = set vars in ADKeys array
    Switch - functional - text and Fn functions - setting vars in Global variables
2024-03-15 Not staged files for previous update
2024-03-21 Functionality improvements
    Fn functions, write text, right pin for analog
2024-03-21 BugFix, design, Save as
    Not supported Czech chars in switch text
    Save as button for config file
2024-03-23 pcb 1x1 sync
    [1x1.kicad_pcb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]
2024-03-24 pcb restored, documentation photos
    [1x1_panel-B_Cu.gbl, 1x1_panel-B_Mask.gbs, 1x1_panel-B_Paste.gbp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]
2024-04-01 rotated pcb, pcb documentation
    [pcb.kicad_pcb, pcb.kicad_sch]
2024-04-09 1x1 pcb update
2024-04-09 1x1 pcb update, pcb docs
    [pcb.kicad_pcb]
2024-04-18 3D models first commit
    [AdaptBoard-Keypad.f3d, MD- 1x1 case.stl, MD- 1x1 lid pot.stl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]
2024-04-20 removed old pcb files, examples in config.py
2026-02-07 add pcb backups folders to itignore
2026-02-07 removed pcb backups
2026-03-02 renamed 3d models, cleaned up 3d models, add keycaps models
    [Body_base.stl, Body_bottom_cover.stl, Body_case.stl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]
